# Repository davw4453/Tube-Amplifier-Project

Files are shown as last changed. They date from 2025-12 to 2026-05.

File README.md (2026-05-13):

# Tube-Amplifier-Project
This is a vacuum tube amplifier with modular input modules to provide for different audio source methods. This project was designed for my captsone project at CCSU.

# Design Requirements 
The design requirement files created as part of the CCSU capstone program are under the DesignRequirementDocs directory. The overall requirements definition is in RequirementsDefinition_DavidWrinn.odt. Each individual module of the system is defined in their respective hardware component specification file. 

# CAUTION
This project uses non-isolated high-voltage US mains power (120V). Be careful of electric shock when constructing and servicing. 

# Build Procedure
These are the steps to construct the project.

1. Have the mainboard and aux input module manufactured at your fab house of choice (JLCPCB, OshPark, etc.).

Mainboard Gerbers: EDAFiles/KiCAD_SCH/tubeAmp/gerbers/
Aux Module Gerbers: EDAFiles/KiCAD_SCH/auxModule/auxModule/gerbers/

2. Assemble the PCBs according to the component designators in the BOM: BOM/tubeAmp_BOM.ods

3. 3D print the case and lid. You can load tubecase.stl and tubecase-lid.3MF into a slicer and print in the material of choice. (I used BambuStudio and printed in clear PLA). The .3mf files are the BambuStudio project files. The .sldprt and .slddrw files are Solidworks CAD files as that is what application I used to design the case and lid. 

4. Mount the boards and components into the case. The mainboard is mounted on M3 standoffs with M3 screws. The lid also uses M3 screws. The speakers are affixed with M4-.70 x 16 screws. The input module should slice in place from the side.

5. Insert a 1A fuse into the power jack, plug in, and enjoy.

Pictures for reference can be found in the Pictures directory. 

# Problems 

- A list of problems can be found in problems.txt.
- Due to inrush current, I had to put an ICL thermistor inline from the main wall supply before the 170VDC rectifier. The part I used was: Vishay Ametherm SL1522102. https://www.digikey.com/en/products/detail/vishay-ametherm/SL1522102/1873476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 
- In a future revision I hope to increase the supply voltage from 170VDC to 300VDC to allow for more power output. 

© 2026 David Wrinn. This work is licensed under CC BY-NC-SA 4.0

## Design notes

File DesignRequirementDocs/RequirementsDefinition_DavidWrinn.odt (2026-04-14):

# System Requirements Definition

## 1. Introduction

### 1.1 Purpose

This document specifies the system requirements for the Vacuum Tube audio amplifier. Its purpose is to transform the high-level stakeholder requirements into a technical view of a required product, defining what the system must possess and how it must perform from a supplier's perspective.

## 2. System Overview

### 2.1 System Boundary and Operational Environment

This section defines the functional boundary of the system. This establishes the expected system behavior at its boundary.

System's Stimuli and Responses

The following user inputs to the system shall be:

- Connect the desired audio source (eg. Phone, CD Player) to the system via line audio connection.
- Tune the desired gain using the provided knob.
- Tune the desired volume level using the provided knob.
- Tune the desired bass level using the provided knob.
- Tune the desired treble level using the provided knob.

The following output responses of the system will be:

- Audio Playback.
  Required Interactions and Interface Constraints

The system constraints are:

- Thermal – The system is not required to be operable below 0°C or above 85°C.
- Electrical – The system is only required to support a power supply of 120V AC.
  Operational Environment

The system will be designed to operate in a primarily indoor environment around room temperature (25°C). It shall also be required to be operable in a mild outdoor environment within the temperatures specified above.

## 3. System Requirements Specification

This section details the required characteristics, attributes, and functional and performance requirements for the product solution.

### 3.1 Functional Requirements

The functions that the system is required to perform are defined as follows:

ID | Function/Requirement Description | Performance/Quantitative Measure
DW-001 | The sound level of the system shall reach at minimum 79 dB SPL | 79dB shall be measured using a sound level test device.
DW-002 | There shall be provisions to attach modules for three types of audio sources: FM Radio, Bluetooth connection, line input via 3.5mm TRS jack. These modules shall be pluggable | The connection provision shall be present on the system and identified.
DW-003 | One of the input modules shall be implemented at time of product launch | Module is present on system.
DW-004 | The gain shall be adjustable at minimum from 0dB to 23 dB through a turn-knob. | Knob is present on the system, identified, and adjusts required level.
DW-005 | The volume shall be adjustable from 10% to 100% signal level through a turn-knob. | Knob is present on the system, identified, and adjusts required level.
DW-006 | The bass shall be adjustable at minimum from -6dB to 6dB through a turn-knob. | Knob is present on the system, identified, and adjusts required level.
DW-007 | The treble shall be adjustable at minimum from -6dB to 6dB through a turn-knob. | Knob is present on the system, identified, and adjusts required level.
DW-008 | The system shall be powered by US mains via a NEMA 1-15 or 5-15P. | The plug is present in the system.

### 3.2 Non-Functional Requirements

The non-functional requirements that the system is required to adhere to are defined as follows:

ID | Requirement Description | Quantitative Measure
DW-009 | All Vacuum tubes in the system shall be visible outside of the product case. | The tubes are visible
DW-010 | Vacuum tubes are connected to the system via socket to allow for easy replacement. | The tubes are socketed.
DW-011 | Schematics are available for troubleshooting purposes | The schematics can be easily found online.
DW-012 | All design files are readily accessible, including but not limited to PCB CAD files, 3d printed case files, analysis and design process documents, BOM. | All design files can be found online in the same location as the schematics.
DW-013 | Project shall be released to the internet via public github and CC BY-NC-SA 4.0 licensed. | Project accessible through github publicly and released with CC BY-NC-SA 4.0 licensing.
DW-014 | The project shall cost at or less than the price of 59 McDonald’s Big Macs to produce | The final constructed unit is produced for at or less than the given price.

## 4. Requirements Analysis and Verification Basis

### 4.1 Integrity

This section demonstrates the process for verification.

#### 4.1.1 Verification Basis

The system requirements will be satisfied and assessed. The following requirements will be verified in the following methods.

- Sound level – A testing apparatus will be used to ensure the sound output reaches 79 dB SPL.
- The input module connections will be present.
- All control knobs will be present.
- The Power connection will be present and accessible.
- All vacuum tubes in the system shall be visible and easily replaced via socket.
- The location of design files shall be known and navigable via the internet.

## 5. Functional Diagram

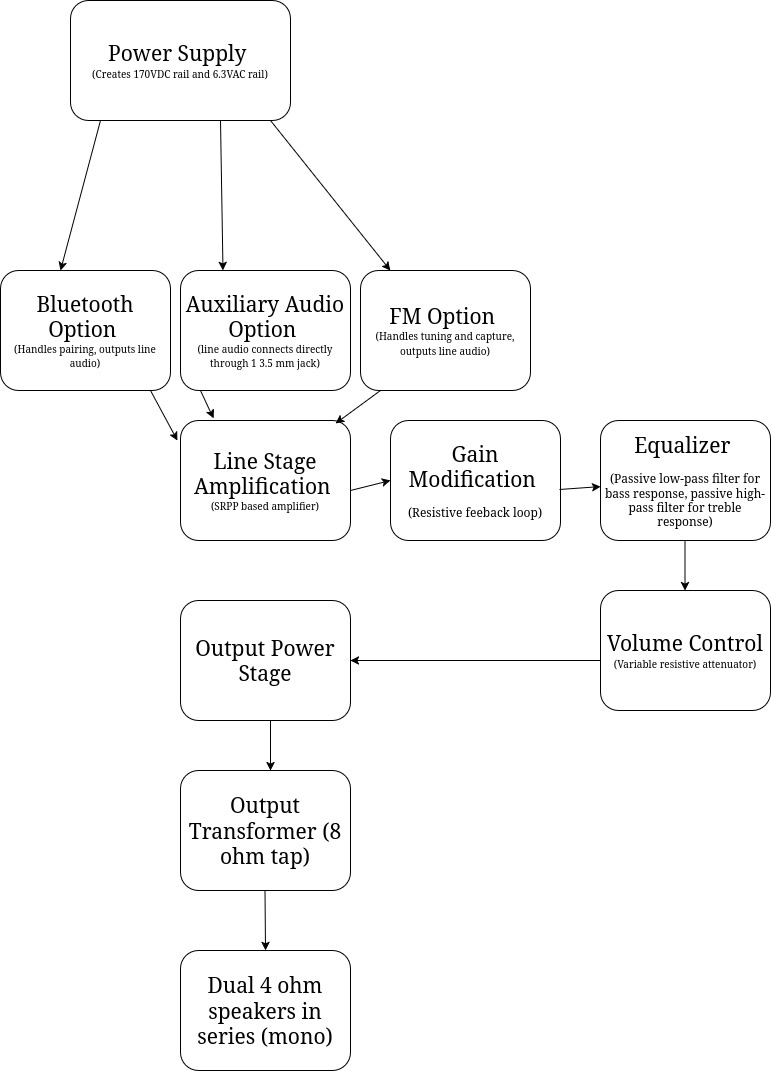
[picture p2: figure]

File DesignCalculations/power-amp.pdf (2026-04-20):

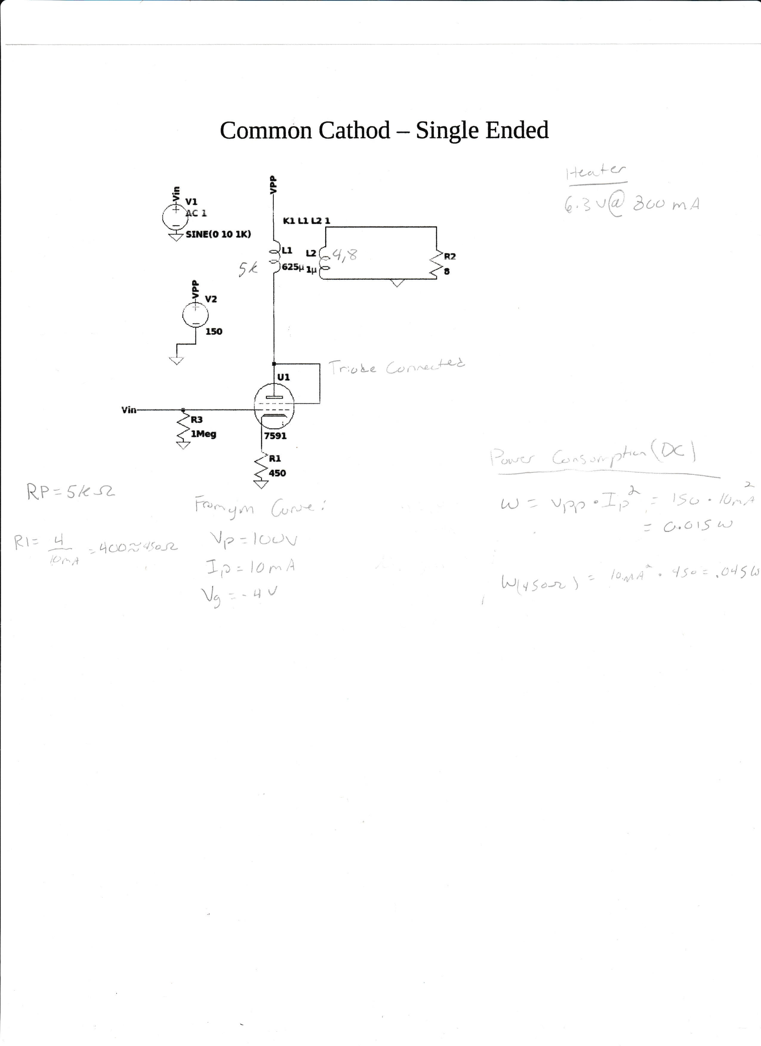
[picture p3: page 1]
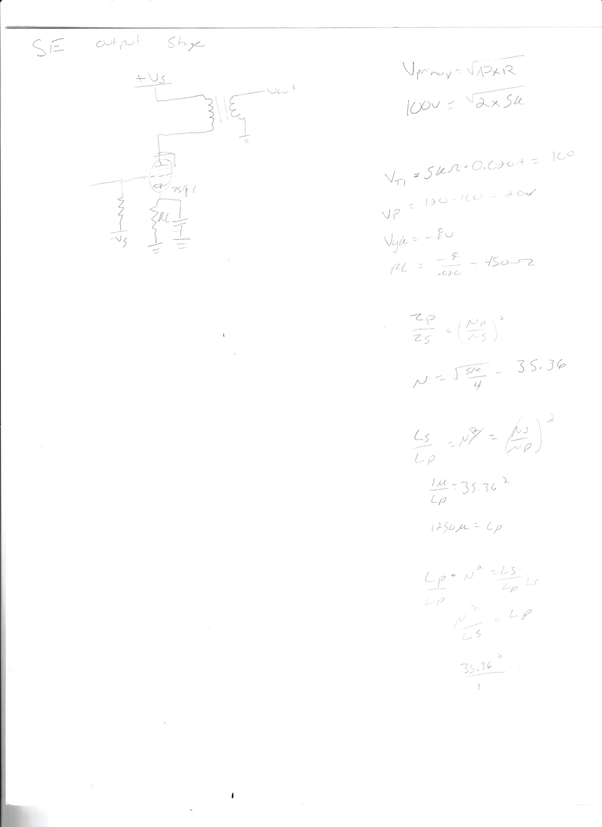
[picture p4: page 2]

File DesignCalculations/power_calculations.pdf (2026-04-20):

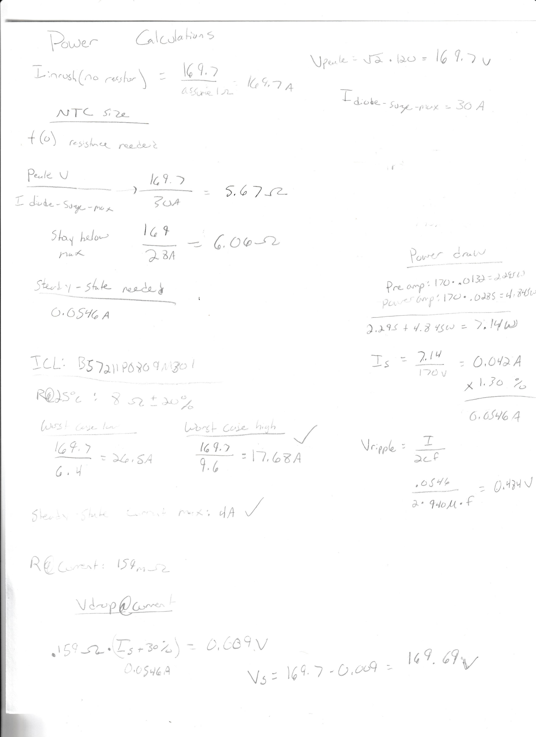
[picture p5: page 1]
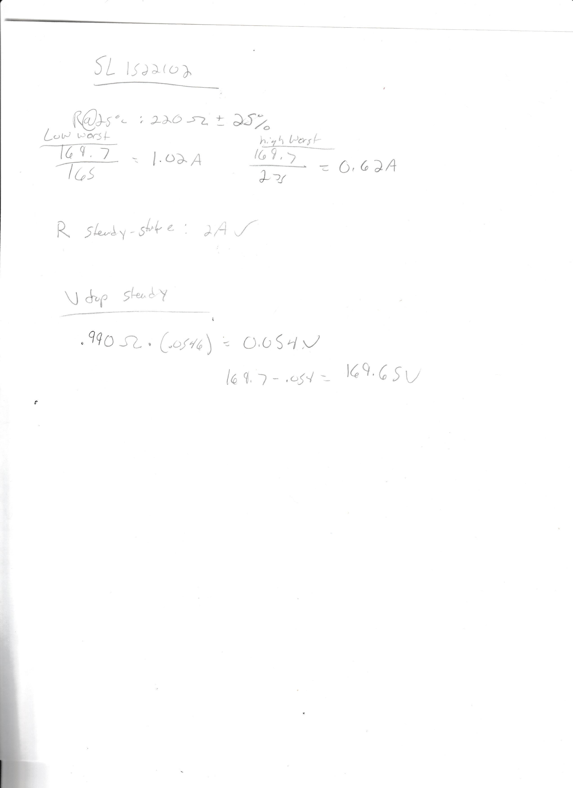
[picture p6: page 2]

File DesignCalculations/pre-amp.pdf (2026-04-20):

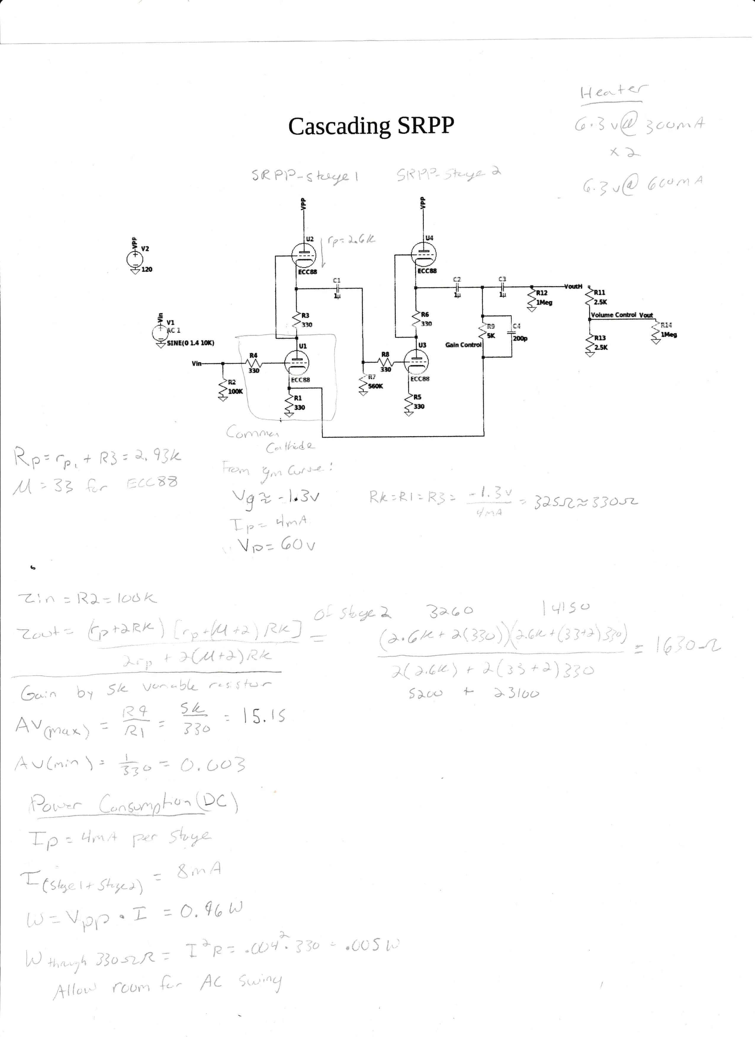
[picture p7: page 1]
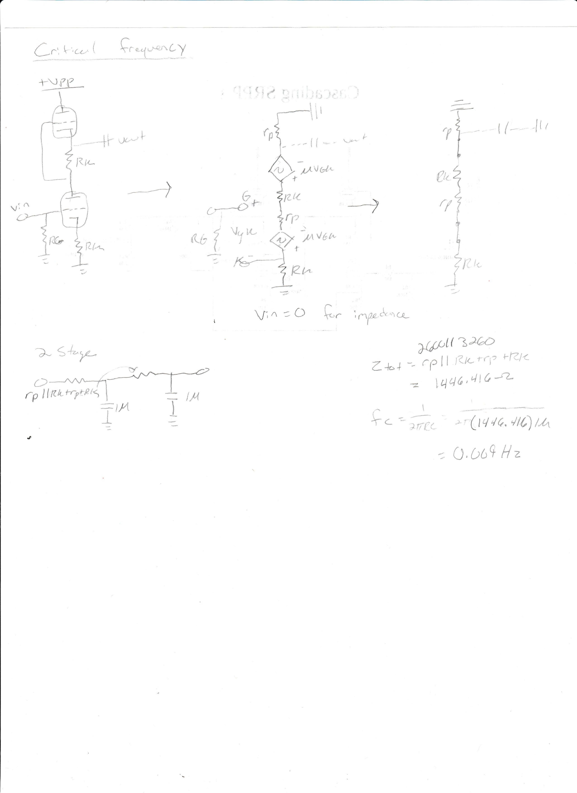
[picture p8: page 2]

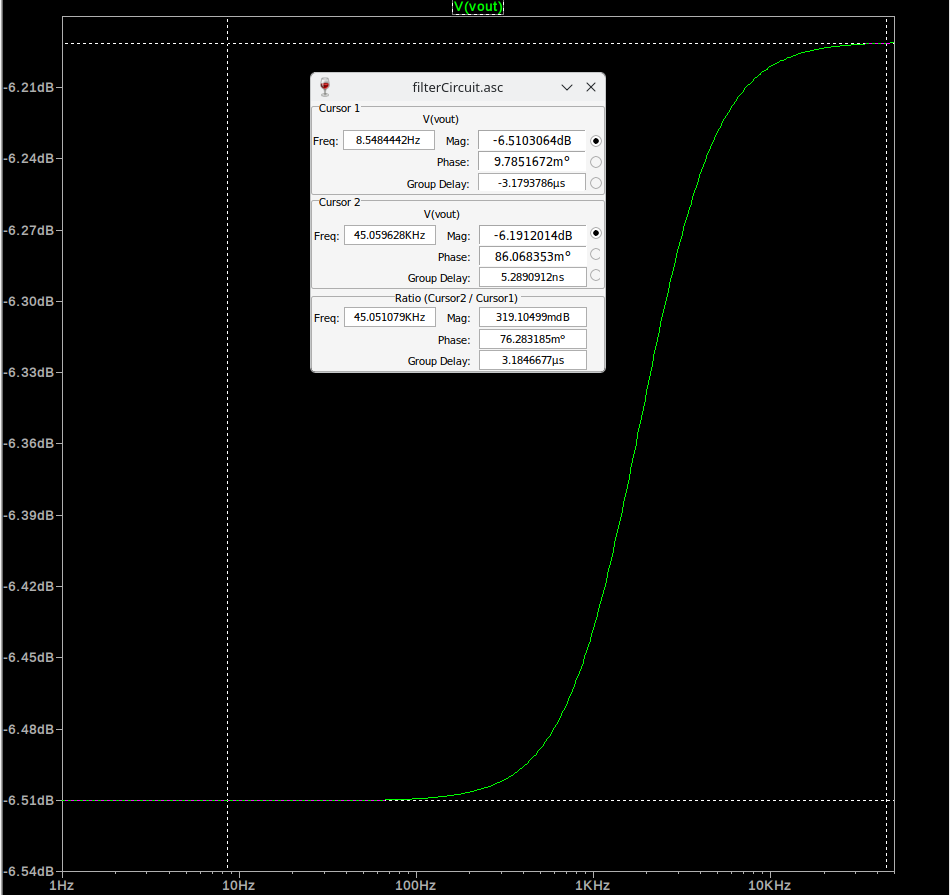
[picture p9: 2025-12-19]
SimulationScreenshots/tonecontrol_flat.png

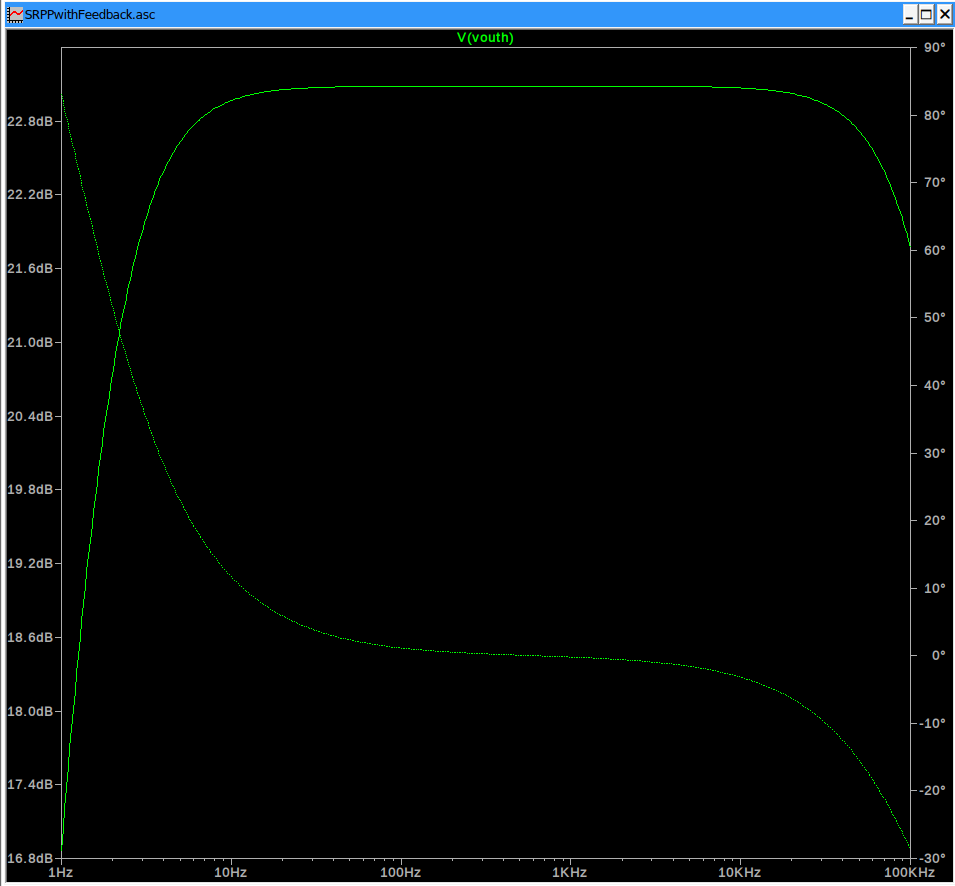
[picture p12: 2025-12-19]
SimulationScreenshots/SRPPwithfeedback_response.png

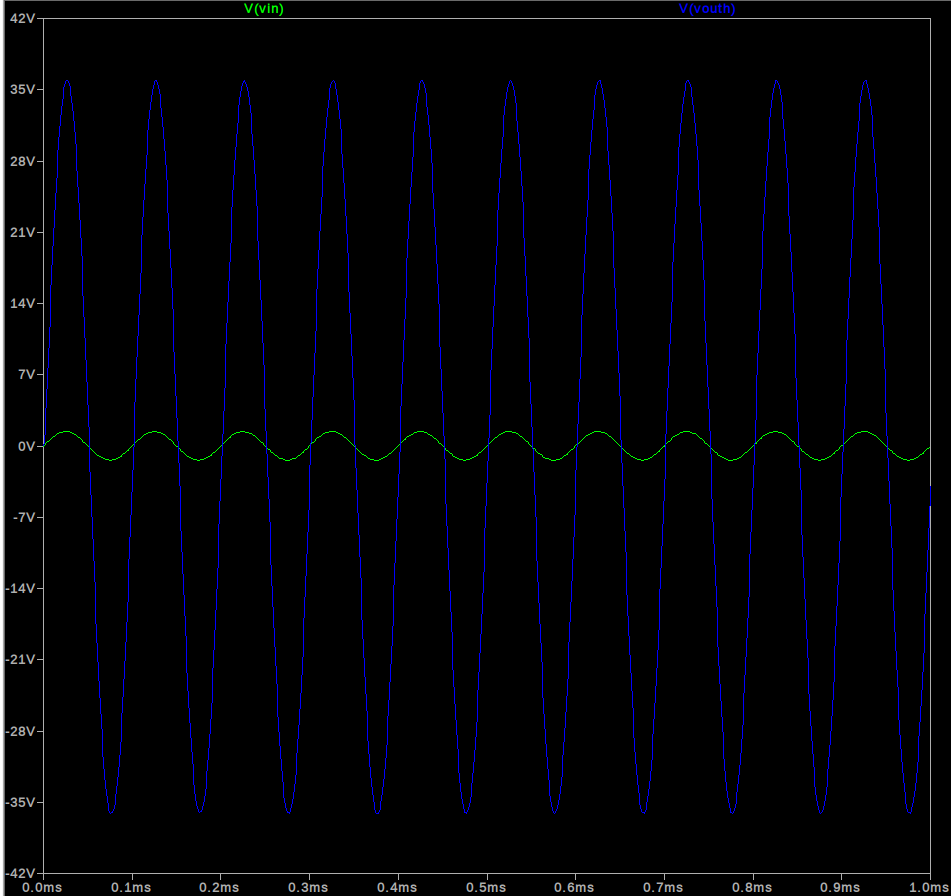
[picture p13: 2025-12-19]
SimulationScreenshots/SRPP_fullgain.png

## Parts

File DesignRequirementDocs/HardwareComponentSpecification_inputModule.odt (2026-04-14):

Hardware Component Specification – Input Module

# Overview and Perspective

## Overview and Key Functions of System

This system is a credit card sized expansion card slot to provide the input signal to the system. It will have a single connector to supply the following to the expansion card: 170VDC, Ground, 6.3VAC (two pin differential), and an auxiliary input signal. A stereo audio signal will be summed together through two 1K resistors to create a mono audio signal for the line-stage amplifier.

## Overview and Purpose of Hardware Component

The purpose of this component is to provide an audio signal to the amplifier, regardless of the source of that audio signal.

## Component Perspective

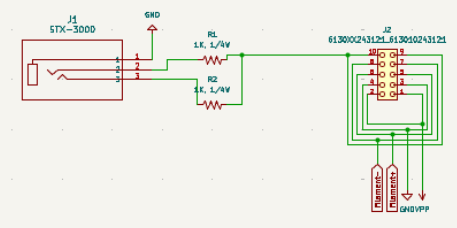
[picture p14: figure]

# Component Details

## Component Part Specification

- Qty. 1 10 Pin IDC connector.

## Signal/Communication Interface(s)

Output:

- Auxiliary Audio

## Power Interface(s)

Input:

- 170VDC power rail
- 6.3VAC power rail

## Key Properties/Functions

The system will output an auxiliary audio signal.

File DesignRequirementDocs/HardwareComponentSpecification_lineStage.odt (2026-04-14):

Hardware Component Specification – Line Stage

# Overview and Perspective

## Overview and Key Functions of System

This system is the first point of contact to amplify an auxillary signal. It is formed by two cascaded SRPP amplifier stages using a 6922/ECC88 dual triode vacuum tube. There is a negative feedback loop fed from the output to the cathode of the first SRPP stage. Gain is controlled by potentiometer RV1, which is a 10K potentiometer with one end bridged to the center, creating a 5K variable resistor. Gain is effectively RV1/R3. The Gain factor can be scaled from 0.003 to 15.15.

## Overview and Purpose of Hardware Component

The purpose of this component is to amplify an auxiliary audio signal to be a suitable level for the power amplification stage and to compensate for the losses from the passive filter circuit.

## Component Perspective

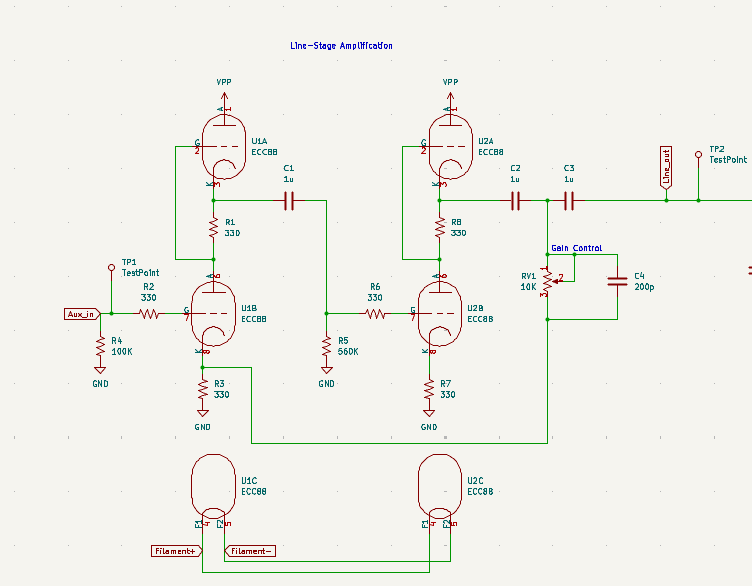
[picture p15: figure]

# Component Details

## Component Part Specification

- Qty. 2 ECC88 vacuum tubes
- Qty. 6 330 ohm 1/4W resistors
- Qty. 1 100K ohm 1/4W resistors
- Qty. 1 560K ohm 1/4W resistors
- Qty. 3 1uF 200V capacitors
- Qty. 1 10K ohm potentiometer
- Qty. 1 200pF 200V capacitor

## Signal/Communication Interface(s)

Input:

- Auxiliary Audio

Output:

- Post line-stage audio signal

## Power Interface(s)

Input:

- 170VDC power rail

## Key Properties/Functions

The system will output an amplified audio signal.

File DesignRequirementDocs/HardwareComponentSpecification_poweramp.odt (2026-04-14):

Hardware Component Specification – Power Amplification

# Overview and Perspective

## Overview and Key Functions of System

This system is the last amplification stage before the audio signal reaches the speaker. It is a single-ended class A amplifier formed by a single stage. The amplifying stage is a triode-connected tetrode vacuum tube in a common-cathode configuration. It feeds an audio transformer to convert the high output impedance from the vacuum tube to a low impedance compatible with 4 and 8 ohm speakers.

## Overview and Purpose of Hardware Component

The purpose of this component is to provide the output power to drive a speaker.

## Component Perspective

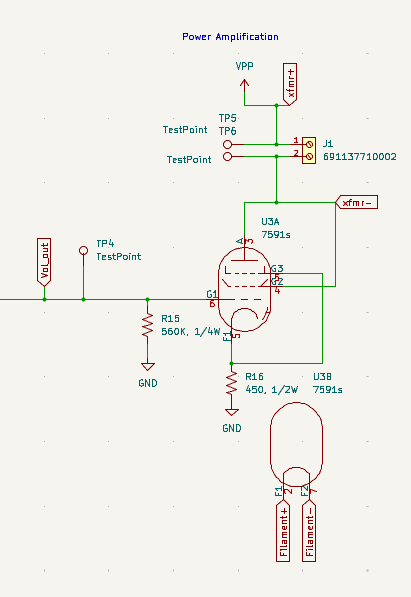
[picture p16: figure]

# Component Details

## Component Part Specification

- Qty. 1 560K 1/4W resistor
- Qty. 1 450 1/2W resistor
- Qty. 1 7591 tetrode vacuum tube
- Qty. 1 OT8SE+ audio transformer

## Signal/Communication Interface(s)

Input:

- post-volume control audio signal

Output:

- Amplified Audio signal to speaker

## Power Interface(s)

Input:

- 170VDC power rail

## Key Properties/Functions

The system will transfer 0-2W of power to a 4 ohm speaker.

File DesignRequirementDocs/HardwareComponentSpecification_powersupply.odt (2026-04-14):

Hardware Component Specification – Power Supply

# Overview and Perspective

## Overview and Key Functions of System

This system is comprised of a filtered full-wave rectifier and a transformer. The rectifier will output 170VDC given a 170Vpp 60 Hz input with a ripple voltage of 51 mV. The transformer will output 6.3VAC given the same 170Vpp input power. The whole system will be capable of delivering 15.5 watts. (Modified to add ICL in-line before C7 and C8 to limit inrush current to around 772 mA.)

## Overview and Purpose of Hardware Component

The purpose of this component is to provide power to all of the sub-circuits of the system.

## Component Perspective

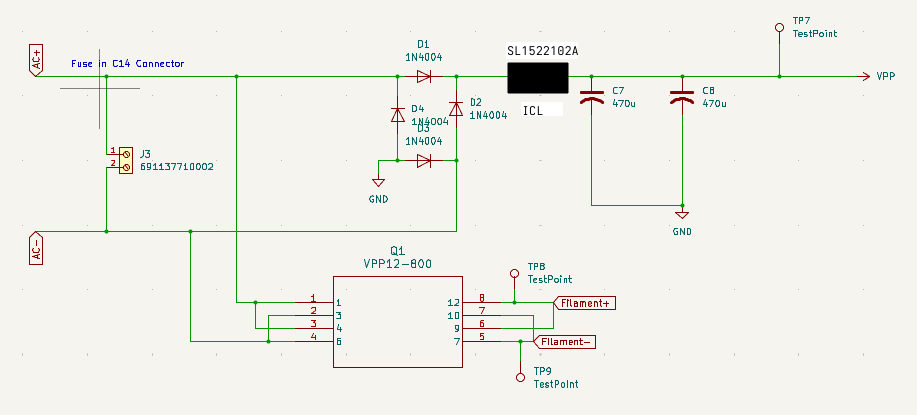
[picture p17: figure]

# Component Details

## Component Part Specification

- Qty. 4 1n4004 diodes
- Qty. 1 Fused C14 connector
- Qty. 1 200 mA fuse
- Qty. 1 120→6.3 V power transformer
- Qty. 2 470uF electrolytic capacitors 200V
- Qty. 1 SL1522102A ICL

## Power Interface(s)

Input:

- North American 120Vrms main power

Output:

- 170VDC power rail
- 6.3VAC power rail

## Key Properties/Functions

The system will transform 120Vrms main power into 170VDC and 6.4VAC derived rails.

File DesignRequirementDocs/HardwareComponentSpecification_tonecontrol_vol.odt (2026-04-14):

Hardware Component Specification – Line Stage

# Overview and Perspective

## Overview and Key Functions of System

This system allows the user to adjust the bass response, treble response, and volume level as desired. It is a passive system, which means the output voltage will be lower than the input voltage. For all three control dials, a 10K potentiometer is used. The bass and treble are adjustable to +/- 6dB. The volume control can attenuate the signal from 0% to 100% with steps of 1%.

## Overview and Purpose of Hardware Component

The purpose of this component is to adjust the bass characteristics, the treble characteristics, and the volume level per the listener’s preference.

## Component Perspective

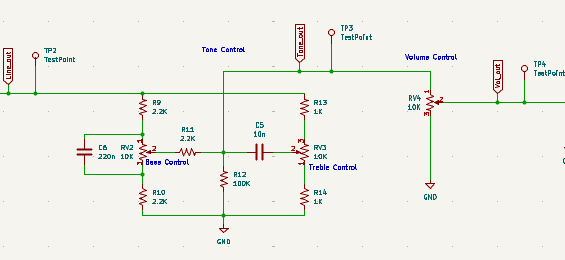
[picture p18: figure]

# Component Details

## Component Part Specification

- Qty. 3 2.2K 1/4W resistors
- Qty. 2 1K 1/4W resistors
- Qty. 1 220nF 50V capacitor
- Qty. 1 10nF 50V capacitor
- Qty. 1 100K ¼W resistor
- Qty. 2 10K ohm potentiometer

## Signal/Communication Interface(s)

Input:

- Post-Line stage audio signal

Output:

- tuned post-line stage audio signal.

## Power Interface(s)

none

## Key Properties/Functions

The system will output a tuned audio signal suitable for power amplification.

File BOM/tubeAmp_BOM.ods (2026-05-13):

MainBoard
Reference | Qty | Value | Footprint | Manufacturer PN | Link | Unit Price | Ext. Price
C1,C2,C3 | 3 | 1u, 100V | Capacitor_THT:CP_Radial_D5.0mm_P2.00mm | ESK105M100AC3AA | https://www.digikey.com/en/products/detail/kemet/esk105m100ac3aa/18167477 | $0.16 | $0.48
C4 | 1 | 200p, 50V | Capacitor_THT:C_Rect_L7.2mm_W5.5mm_P5.00mm_FKS2_FKP2_MKS2_MKP2 | C317C201J5G5TA7301 | https://www.mouser.com/ProductDetail/KEMET/C317C201J5G5TA7301?qs=2FIyTMJ0hNno2fk56OoQRA%3D%3D | $0.62 | $0.62
C5 | 1 | 10n, 50V | Capacitor_THT:C_Rect_L7.2mm_W5.5mm_P5.00mm_FKS2_FKP2_MKS2_MKP2 | FG28C0G1H103JNT06 | https://www.digikey.com/en/products/detail/tdk-corporation/FG28C0G1H103JNT06/5803088 | $0.35 | $0.35
C6 | 1 | 220n, 50V | Capacitor_THT:C_Rect_L7.2mm_W5.5mm_P5.00mm_FKS2_FKP2_MKS2_MKP2 | FG22C0G1H224JNT00 | https://www.digikey.com/en/products/detail/tdk-corporation/FG22C0G1H224JNT00/7326573 | $1.47 | $1.47
C7,C8 | 2 | 470u, 200V | Capacitor_THT:CP_Radial_D18.0mm_P7.50mm | EPAG201ELL471MM40S | https://www.digikey.com/en/products/detail/chemi-con/EPAG201ELL471MM40S/3983309 | $3.02 | $6.04
D1,D2,D3,D4 | 4 | 1N4004 | Diode_THT:D_DO-41_SOD81_P10.16mm_Horizontal | 1N4004 | https://www.mouser.com/ProductDetail/Diotec-Semiconductor/1N4004?qs=OlC7AqGiEDk3eaZusDVIWQ%3D%3D | $0.10 | $0.40
J1,J3 | 2 | 691137710002 | DavidWrinn:691137710002-2screw | 691137710002 | https://www.digikey.com/en/products/detail/w%C3%BCrth-elektronik/691137710002/6644051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 | $0.36 | $0.72
J2 | 1 | 702471054 | DavidWrinn:CONN_7024710xx_10pos | 702471054 | https://www.digikey.com/en/products/detail/molex/0702471054/3302078?s=N4IgTCBcDaIOwAYwBY4EYEFZkgLoF8g | $2.37 | $2.37
Q1 | 1 | VPP12-800 | DavidWrinn:TRANS_VPP12-800_TRM | VPP12-800 | https://www.digikey.com/en/products/detail/triad-magnetics/VPP12-800/242498 | $10.06 | $10.06
R1,R2,R3,R6,R7,R8 | 6 | 330, 1/4W | Resistor_THT:R_Axial_DIN0207_L6.3mm_D2.5mm_P10.16mm_Horizontal | CF14JT330R | https://www.digikey.com/en/products/detail/stackpole-electronics-inc/CF14JT330R/1741399 | $0.10 | $0.60
R4,R12 | 2 | 100K, 1/4W | Resistor_THT:R_Axial_DIN0207_L6.3mm_D2.5mm_P10.16mm_Horizontal | CF14JT100K | https://www.digikey.com/en/products/detail/stackpole-electronics-inc/CF14JT100K/1741263 | $0.10 | $0.20
R5,R15 | 2 | 560K, 1/4W | Resistor_THT:R_Axial_DIN0207_L6.3mm_D2.5mm_P10.16mm_Horizontal | CF14JT560K | https://www.digikey.com/en/products/detail/stackpole-electronics-inc/CF14JT560K/1741468 | $0.10 | $0.20
R9,R10,R11 | 3 | 2.2K, 1/4W | Resistor_THT:R_Axial_DIN0207_L6.3mm_D2.5mm_P10.16mm_Horizontal | CF14JT2K20 | https://www.digikey.com/en/products/detail/stackpole-electronics-inc/CF14JT2K20/1741321 | $0.10 | $0.30
R13,R14 | 2 | 1K, 1/4W | Resistor_THT:R_Axial_DIN0207_L6.3mm_D2.5mm_P10.16mm_Horizontal | CF14JT1K00 | https://www.digikey.com/en/products/detail/stackpole-electronics-inc/CF14JT1K00/1741314 | $0.10 | $0.20
R16 | 1 | 450, 1/2W | Resistor_THT:R_Axial_DIN0309_L9.0mm_D3.2mm_P12.70mm_Horizontal | MFR50SFTE52-442R | https://www.digikey.com/en/products/detail/yageo/MFR50SFTE52-442R/9151526 | $0.10 | $0.10
RV1,RV2,RV3,RV4 | 4 | 10K, 1/4W | Connector_PinHeader_2.54mm:PinHeader_1x03_P2.54mm_Vertical | PTN24B-B1015K1PB | https://www.digikey.com/en/products/detail/same-sky-formerly-cui-devices/PTN24B-B1015K1PB/22255103 | $1.45 | $5.80
TP1,TP2,TP3,TP4,TP5,TP6,TP7,TP8,TP9 | 9 | TestPoint | TestPoint:TestPoint_Pad_D1.5mm
U1,U2 | 2 | ECC88 | Valve:Valve_Noval_P | 6922EH | https://www.vivatubes.com/brand-new-gain-tested-electro-harmonix-6922-6dj8-vacuum-tube/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 | $21.92 | $43.84
U3 | 1 | 7591s | Wheat:OCTAL | 7591S | https://www.vivatubes.com/new-jj-7591-vacuum-tube/?searchid=0&search_query=7591s | $28.37 | $28.37
U1,U2 Socket | 2 | ECC88 |  | B9A | https://www.amazon.com/lanema-Ceramic-Mount-Socket-Vacuum/dp/B0CGTVRS7P | $1.02 | $2.04
U3 Socket | 1 | 7591s |  | Octal | https://www.amazon.com/JEMOSA-Bakelite-Amplifier-Vacuum-Protect/dp/B0CCMGSRRD | $2.95 | $2.95
External Connections
Reference | Qty | Value | Footprint | Manufacturer PN | Link | Unit Price
F1 | 1 | 1A |  | Need to choose PN | 1A 5mm x 20mm fuse | $1.19 | $1.19
J1 | 1 | 723W-X2/04 |  | 723W-X2/04 | https://www.digikey.com/en/products/detail/qualtek/723W-X2-04/245547?s=N4IgTCBcDaIOxgMwHcC0APMB6ADAFhAF0BfIA | $2.67 | $2.67
LS1,LS2 | 2 | 4 |  | CSS-10237-54 | https://www.digikey.com/en/products/detail/same-sky-formerly-cui-devices/CSS-10237-54/12762237 | $8.28 | $16.56
TR1 | 1 | MPS OT8SE+ | Transformer_THT:Transformer_Breve_TEZ-22x24 | MPS OT8SE+ | https://www.ebay.com/itm/167716877031?_skw=musical+power+supplies+ot8se%2B&itmmeta=01K9FETDF6CQ9TKCFDS6SRV0VM | $34.95 | $34.95
 | 1 | 22AWG, 25’ |  | 8023 | https://www.digikey.com/en/products/detail/sparkfun-electronics/08023/6833929 | $3.44 | $3.44
 | 1 | Spade connector 6.3mm, 100 pack |  | Baomain 100-Pack | https://www.amazon.com/Baomain-disconnects-Insulated-Connector-Electrical/dp/B01G4POUAU | $6.64 | $6.64
 | 1 | Clear PLA |  | Elegoo Translucent PLA | https://www.amazon.com/ELEGOO-Filament-Translucent-Dimensional-Cardboard/dp/B0DM1QTZKN | $18.99 | $18.99
 | 1 | 4pcs Aluminum Knobs |  | 4Pcs Aluminum Knobs | https://www.amazon.com/gp/aw/d/B0B2ZYBPXB/?aaxitk=a0cbd2bfeb396e95dc7557d5a0cb5391&hsa_cr_id=0 | $17.99 | $17.99
SW1 | 1 | SW_SPST |  | MTS-101 | https://www.amazon.com/dp/B0799LBFNY?th=1 | $0.80 | $0.80
Aux Input Module
Reference | Qty | Value | Footprint | Manufacturer PN | Link | Unit Cost
J1 | 1 | STX-3000 | STX-3000_KYC | STX-3000 | https://www.digikey.com/en/products/detail/kycon-inc/STX-3000/9975995?s=N4IgTCBcDaIMoBUAaBaAzABiyAugXyA | $0.64 | $0.64
J2 | 1 | 6130XX243121_613010243121 | DavidWrinn:613010243121_10pin | 613010243121 | https://www.digikey.com/en/products/detail/w%C3%BCrth-elektronik/613010243121/2508634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 | $1.00 | $1.00
R1,R2 | 2 | 1K, 1/4W | Resistor_THT:R_Axial_DIN0207_L6.3mm_D2.5mm_P10.16mm_Horizontal | CF14JT1K00 | https://www.digikey.com/en/products/detail/stackpole-electronics-inc/CF14JT1K00/1741314 | $0.10 | $0.20
 |  |  |  |  | Complete Sub-total (minus pcb manufacturing costs) |  | $212.18
 |  |  |  |  |  |  | $4.00

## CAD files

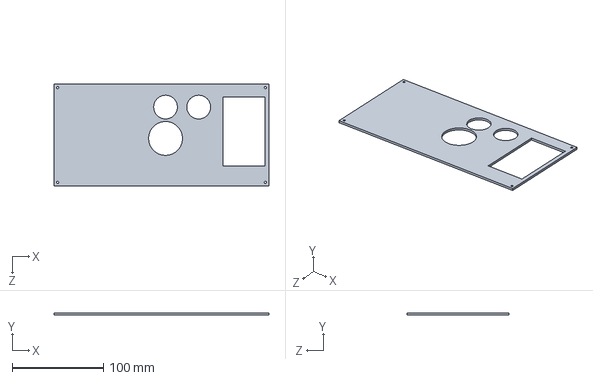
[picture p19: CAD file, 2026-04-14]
CaseDrawings/tubecase-lid.sldprt
235.9 x 2.50 x 111.9 mm

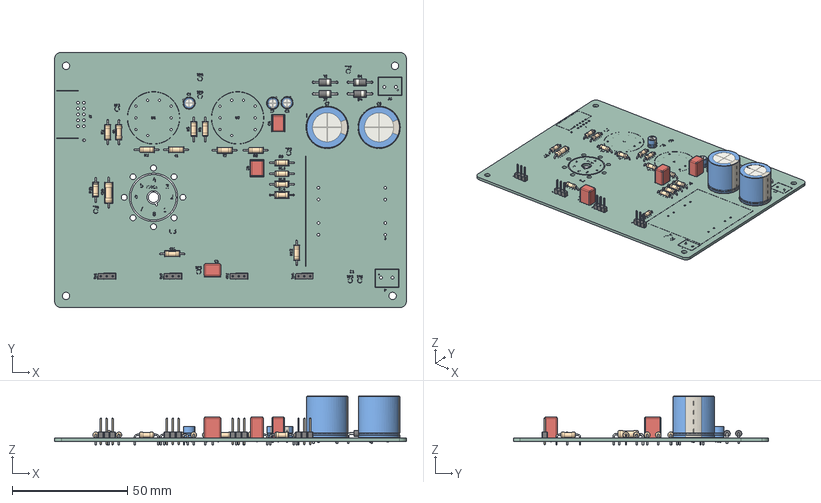
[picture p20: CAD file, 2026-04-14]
EDAFiles/KiCAD_SCH/tubeAmp/board-outline.step
152.4 x 110.6 x 21.0 mm
PinHeader_1x03_P2.54mm_Vertical x 4
D_DO-41_SOD81_P10.16mm_Horizontal x 4
R_Axial_DIN0207_L6.3mm_D2.5mm_P10.16mm_Horizontal x 15
CP_Radial_D18.0mm_P7.50mm x 2
CP_Radial_D5.0mm_P2.00mm x 3
C_Rect_L7.2mm_W5.5mm_P5.00mm_FKS2_FKP2_MKS2_MKP2 x 3
R_Axial_DIN0309_L9.0mm_D3.2mm_P12.70mm_Horizontal
tubeAmp_silkscreen x 2
tubeAmp_PCB

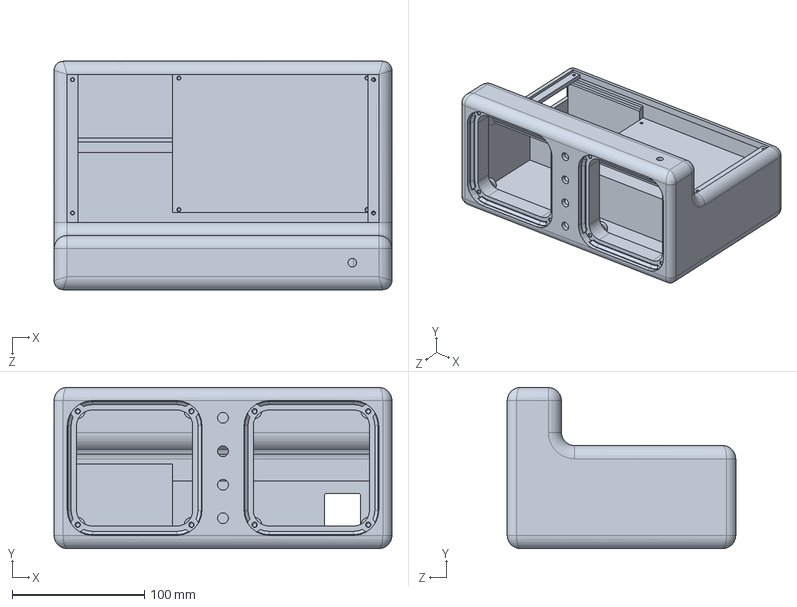
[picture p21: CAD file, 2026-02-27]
CaseDrawings/case-as-one.SLDPRT
256.0 x 122.0 x 173.1 mm

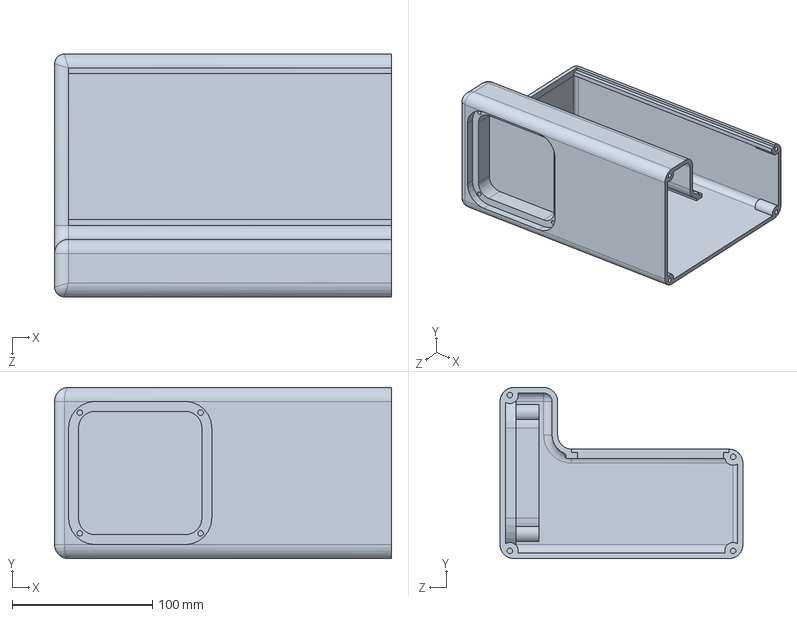
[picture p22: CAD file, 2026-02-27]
CaseDrawings/case-left.SLDPRT
240.1 x 122.0 x 173.1 mm

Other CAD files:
CaseDrawings/tubecase.3mf
CaseDrawings/case-as-one.SLDDRW
CaseDrawings/tubecase-lid.3MF
CaseDrawings/tubecase-lid.3mf
CaseDrawings/tubecase-lid.slddrw
CaseDrawings/tubecase.stl

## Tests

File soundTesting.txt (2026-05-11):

smells like teen spirit

hmdx - max 73db
beats pill - max 85.8dB
tube amp - 78.3 dB

Tested at 10ft distance

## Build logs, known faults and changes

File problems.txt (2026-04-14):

two mounting holes not bonded to ground
main power traces too thin
7591s footprint doesn't fit
6922 footprints doesn't fit well
Provision series resistor add-in to 6.3VAC secondary.
add common mode choke
add icl/soft start DC
thicken traces because it makes me feel better
pots that aren't switches

aux input module connector needs to overhang + flip sides for case.

CASE
speaker holes too small
control pots too small
input module slot to narrow
speaker indent wall doesn't print well
Case wall to thick to skrew in pot securing nuts.
lid lip overhangs PCB on power side.

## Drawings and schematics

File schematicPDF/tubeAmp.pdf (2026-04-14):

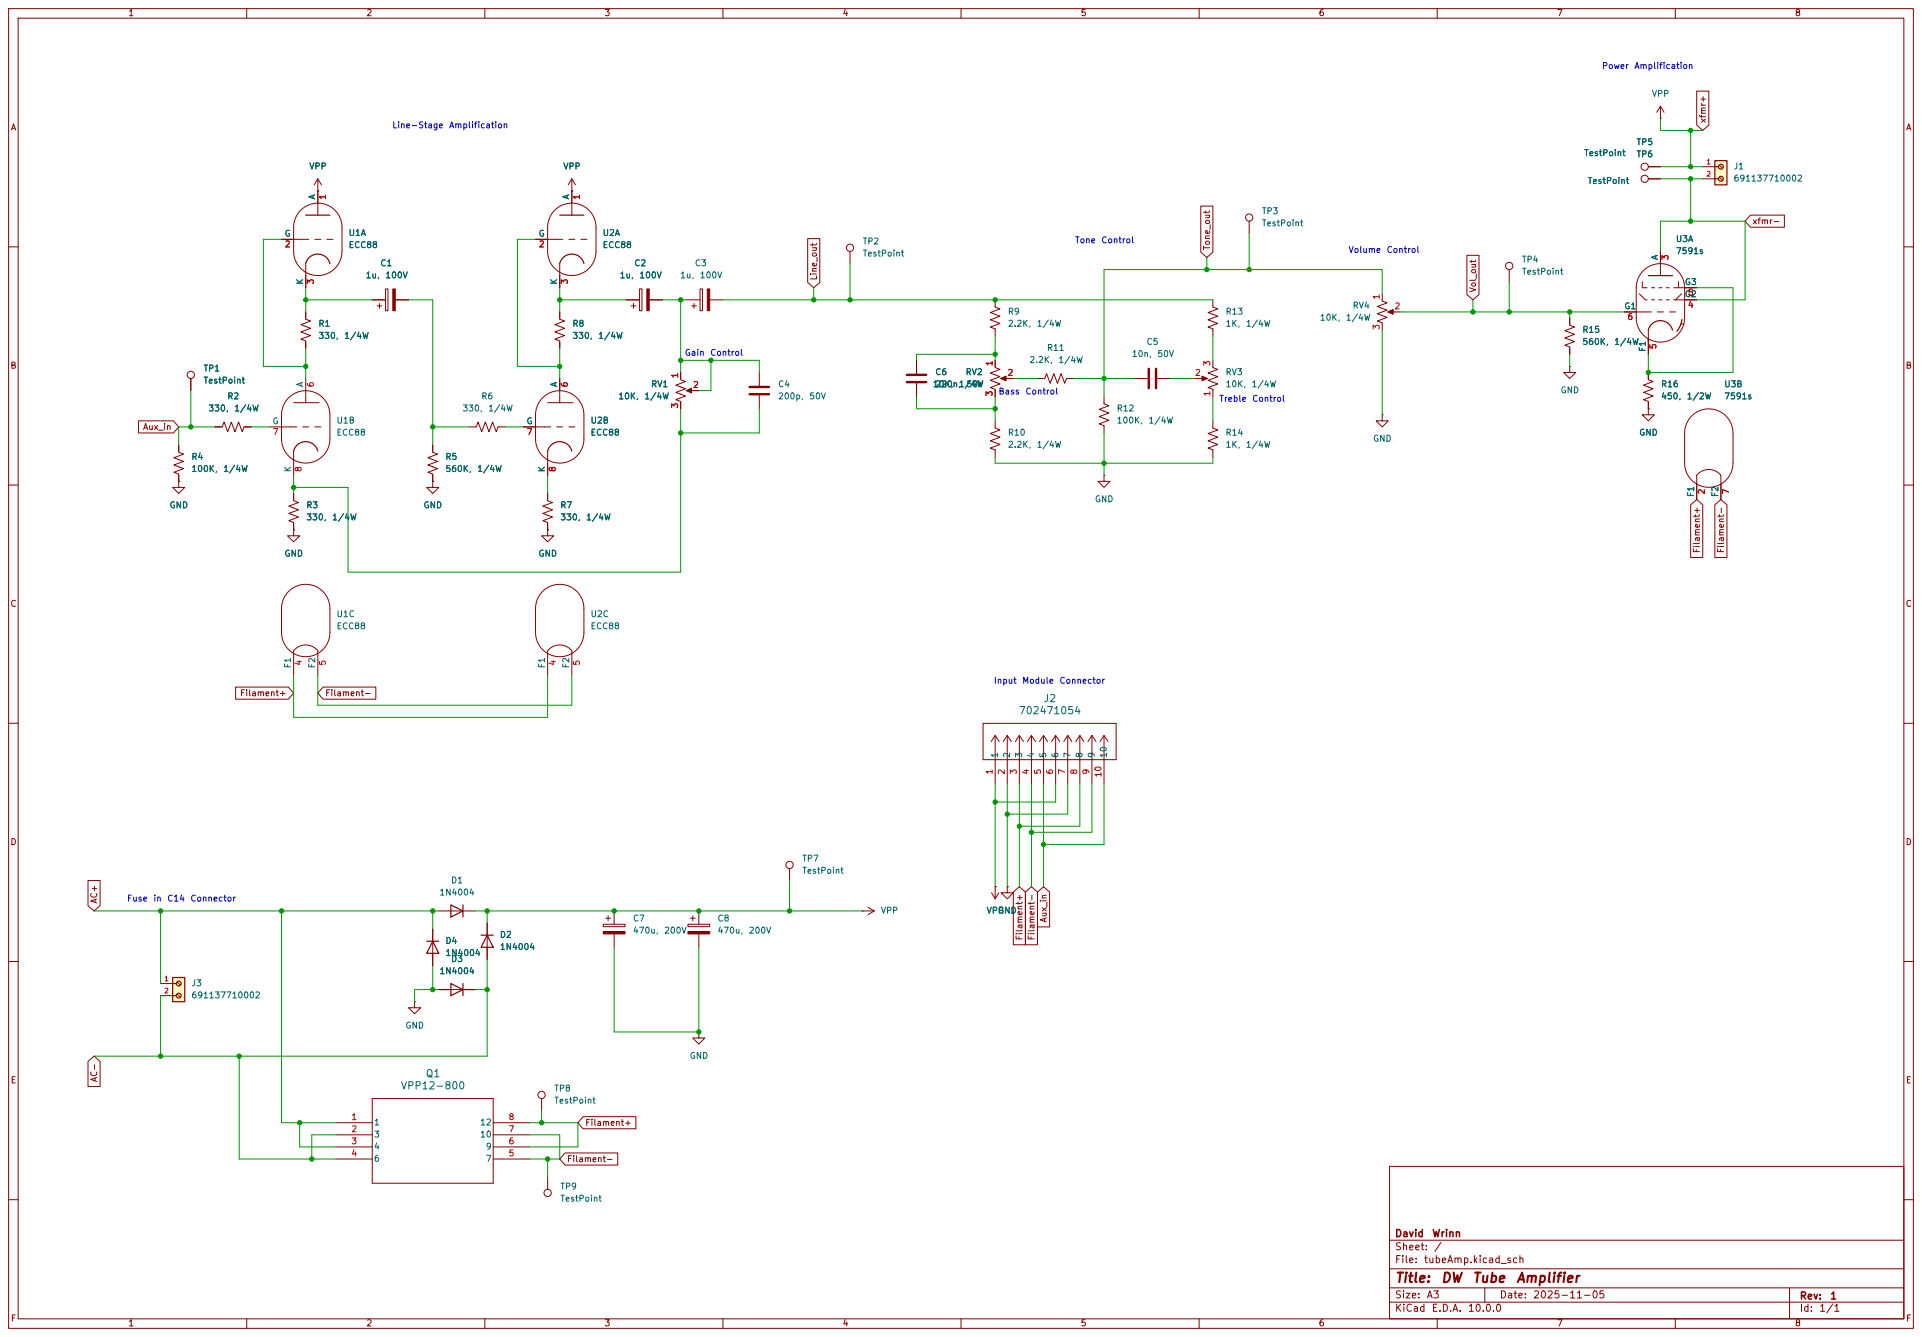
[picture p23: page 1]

Line-Stage Amplification GND

David Wrinn
Sheet: /
File: tubeAmp.kicad_sch
Title: DW Tube Amplifier

Size: A3 | Rev: 1 | F Date: 2025-11-05 KiCad E.D.A. 10.0.0

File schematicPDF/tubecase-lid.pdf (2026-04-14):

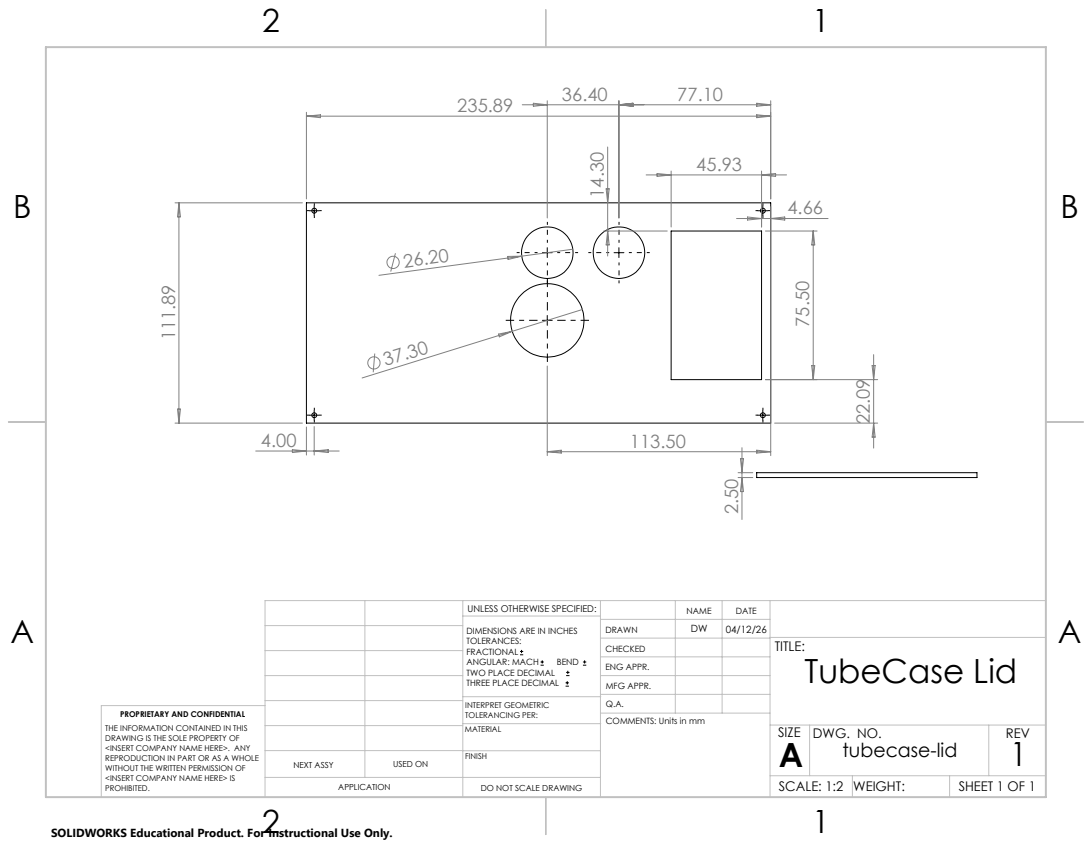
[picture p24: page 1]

UNLESS OTHERWISE SPECIFIED: | | NAME | DATE
DIMENSIONS ARE IN INCHES TOLERANCES: FRACTIONAL ANGULAR: MACH BEND TWO PLACE DECIMAL THREE PLACE DECIMAL | DRAWN | DW | 04/12/26

CHECKED | | | TITLE: TubeCase Lid

ENG APPR.
MFG APPR.

INTERPRET GEOMETRIC TOLERANCING PER: | Q.A.
MATERIAL | | SIZE A | DWG. NO. tubecase-lid | REV 1

PROPRIETARY AND CONFIDENTIAL
THE INFORMATION CONTAINED IN THIS
DRAWING IS THE SOLE PROPERTY OF
<INSERT COMPANY NAME HERE>. ANY
REPRODUCTION IN PART OR AS A WHOLE
WITHOUT THE WRITTEN PERMISSION OF
<INSERT COMPANY NAME HERE> IS
PROHIBITED.

COMMENTS: Units in mm

NEXT ASSY | USED ON | FINISH

APPLICATION | DO NOT SCALE DRAWING | | SCALE: 1:2 | WEIGHT: | SHEET 1 OF 1

SOLIDWORKS Educational Product. For Instructional Use Only.

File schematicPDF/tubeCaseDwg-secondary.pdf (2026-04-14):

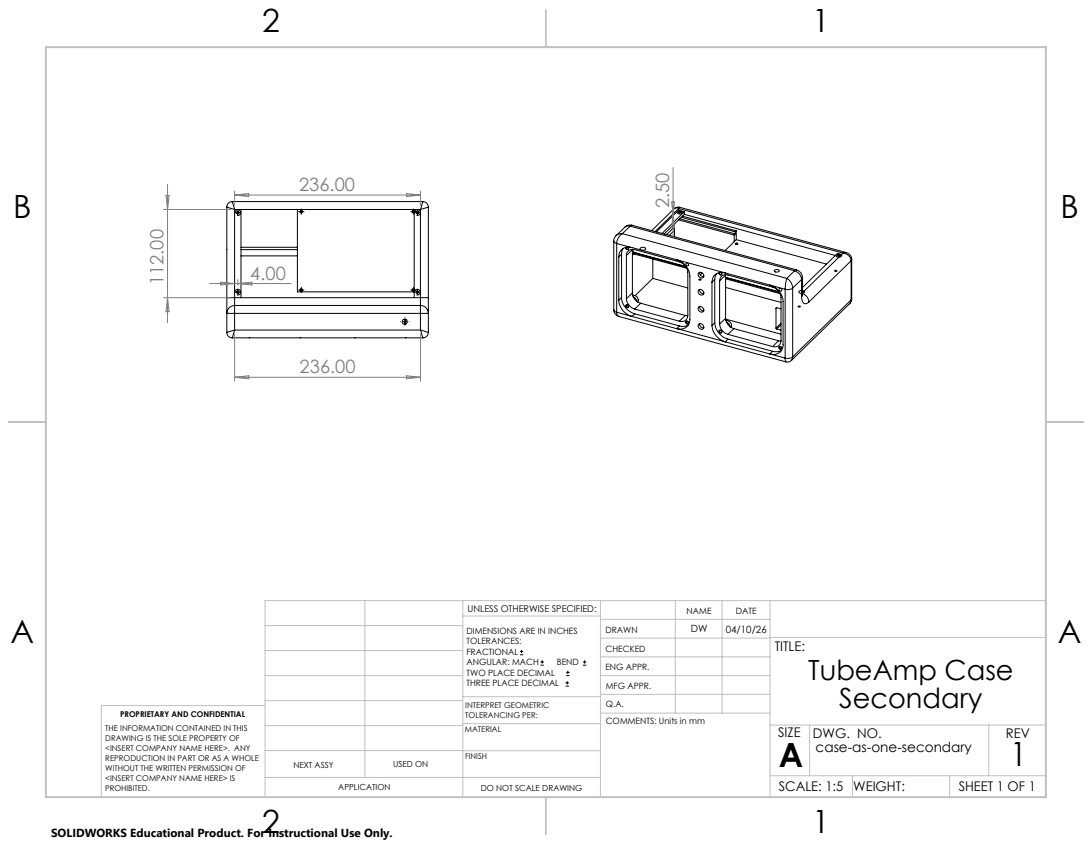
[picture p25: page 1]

UNLESS OTHERWISE SPECIFIED: | | NAME | DATE
DIMENSIONS ARE IN INCHES TOLERANCES: FRACTIONAL ANGULAR: MACH BEND TWO PLACE DECIMAL THREE PLACE DECIMAL | DRAWN | DW | 04/10/26

CHECKED | | | TITLE: TubeAmp Case Secondary

ENG APPR.
MFG APPR.

INTERPRET GEOMETRIC TOLERANCING PER: | Q.A.
MATERIAL | | SIZE A | DWG. NO. case-as-one-secondary | REV 1

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

COMMENTS: Units in mm

NEXT ASSY | USED ON | FINISH

APPLICATION | DO NOT SCALE DRAWING | | SCALE: 1:5 | WEIGHT: | SHEET 1 OF 1

SOLIDWORKS Educational Product. For Instructional Use Only.

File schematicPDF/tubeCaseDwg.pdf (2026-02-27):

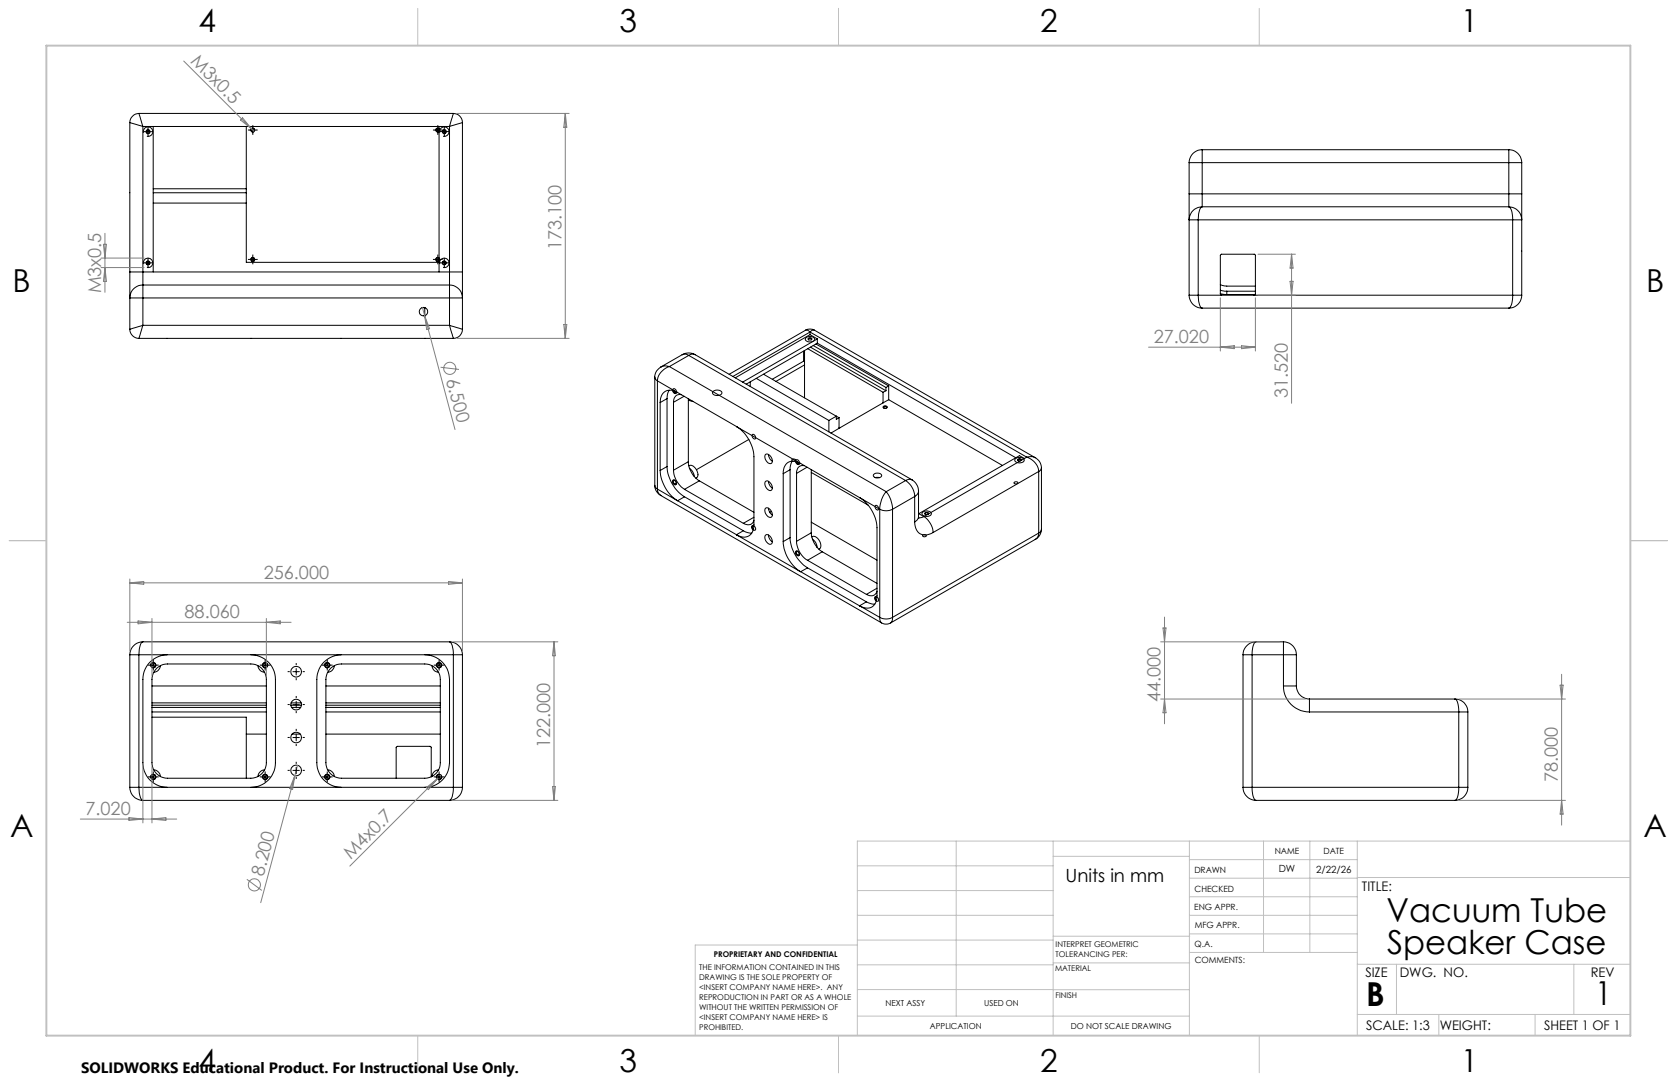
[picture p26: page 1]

NAME | DATE
CHECKED | | | TITLE: Vacuum Tube Speaker Case

Units in mm | DRAWN | DW | 2/22/26

ENG APPR.
MFG APPR.

INTERPRET GEOMETRIC TOLERANCING PER: | Q.A.
MATERIAL | | SIZE B | DWG. NO. | REV 1

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

NEXT ASSY | USED ON | FINISH

APPLICATION | DO NOT SCALE DRAWING | | SCALE: 1:3 | WEIGHT: | SHEET 1 OF 1

SOLIDWORKS Educational Product. For Instructional Use Only.

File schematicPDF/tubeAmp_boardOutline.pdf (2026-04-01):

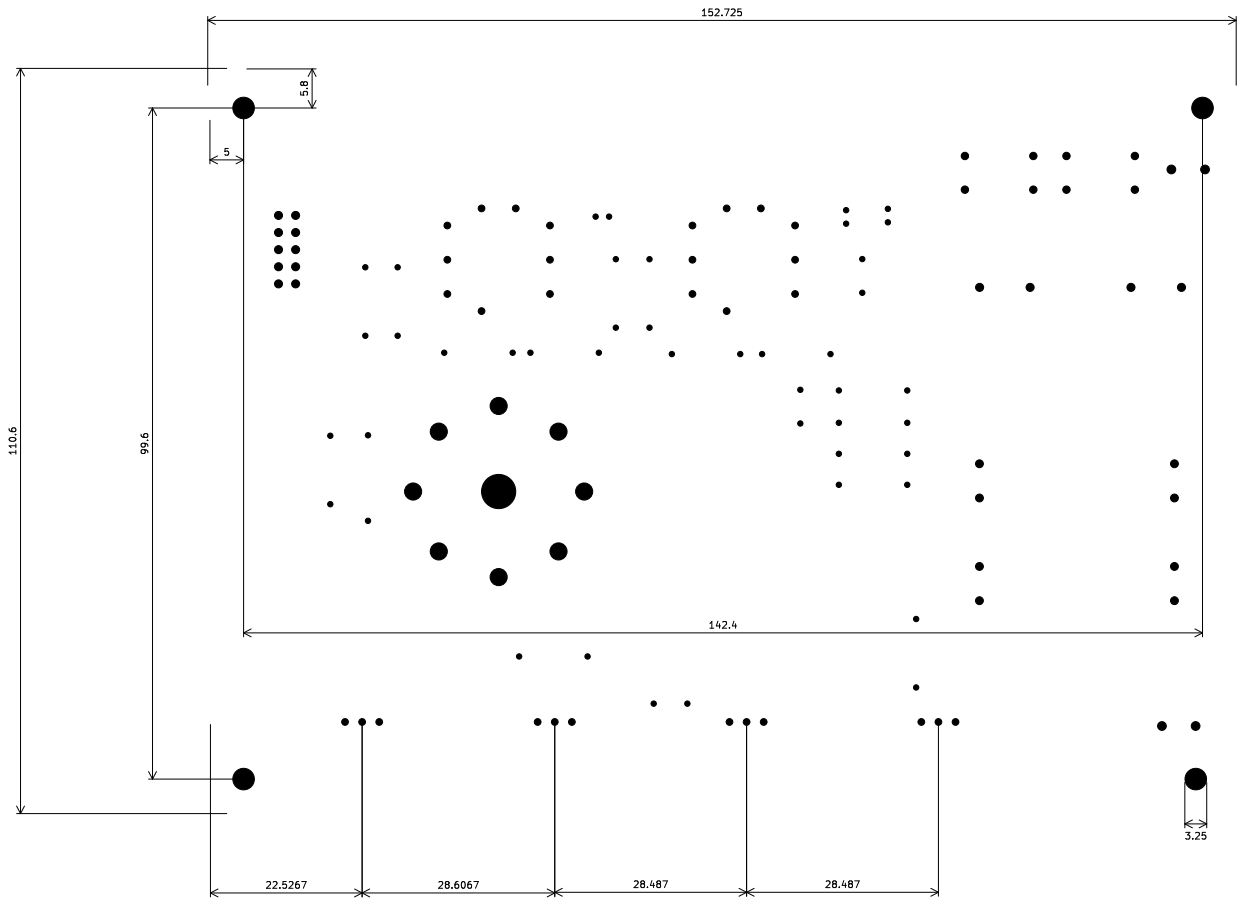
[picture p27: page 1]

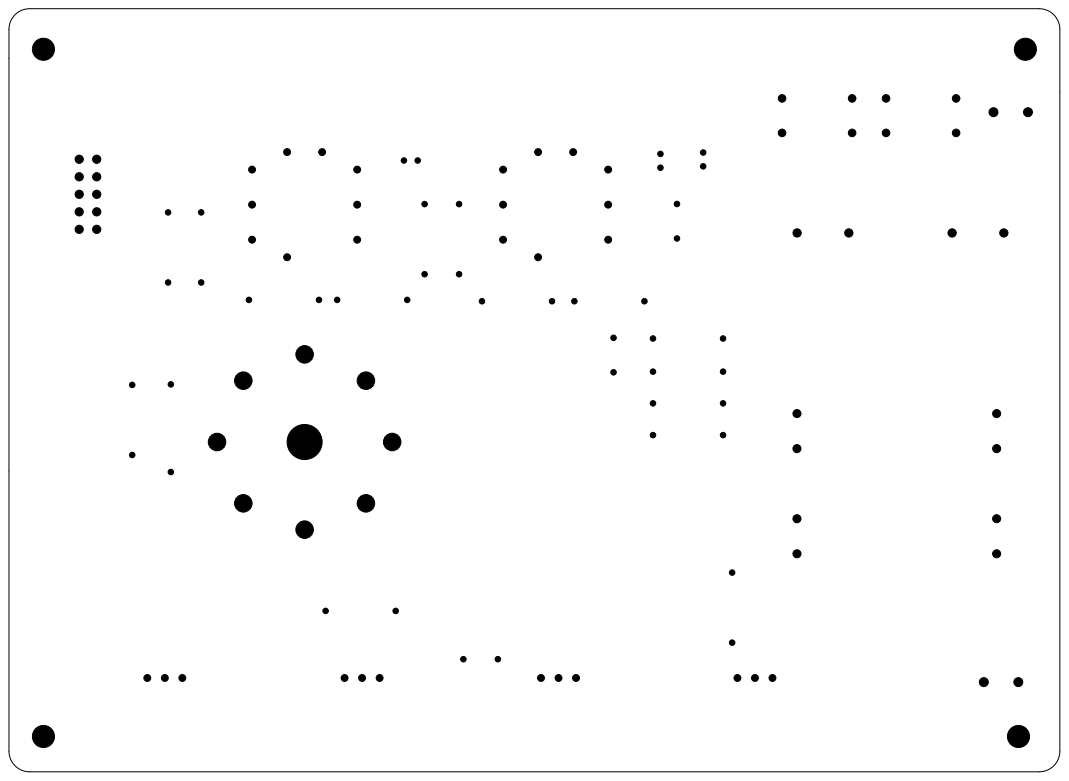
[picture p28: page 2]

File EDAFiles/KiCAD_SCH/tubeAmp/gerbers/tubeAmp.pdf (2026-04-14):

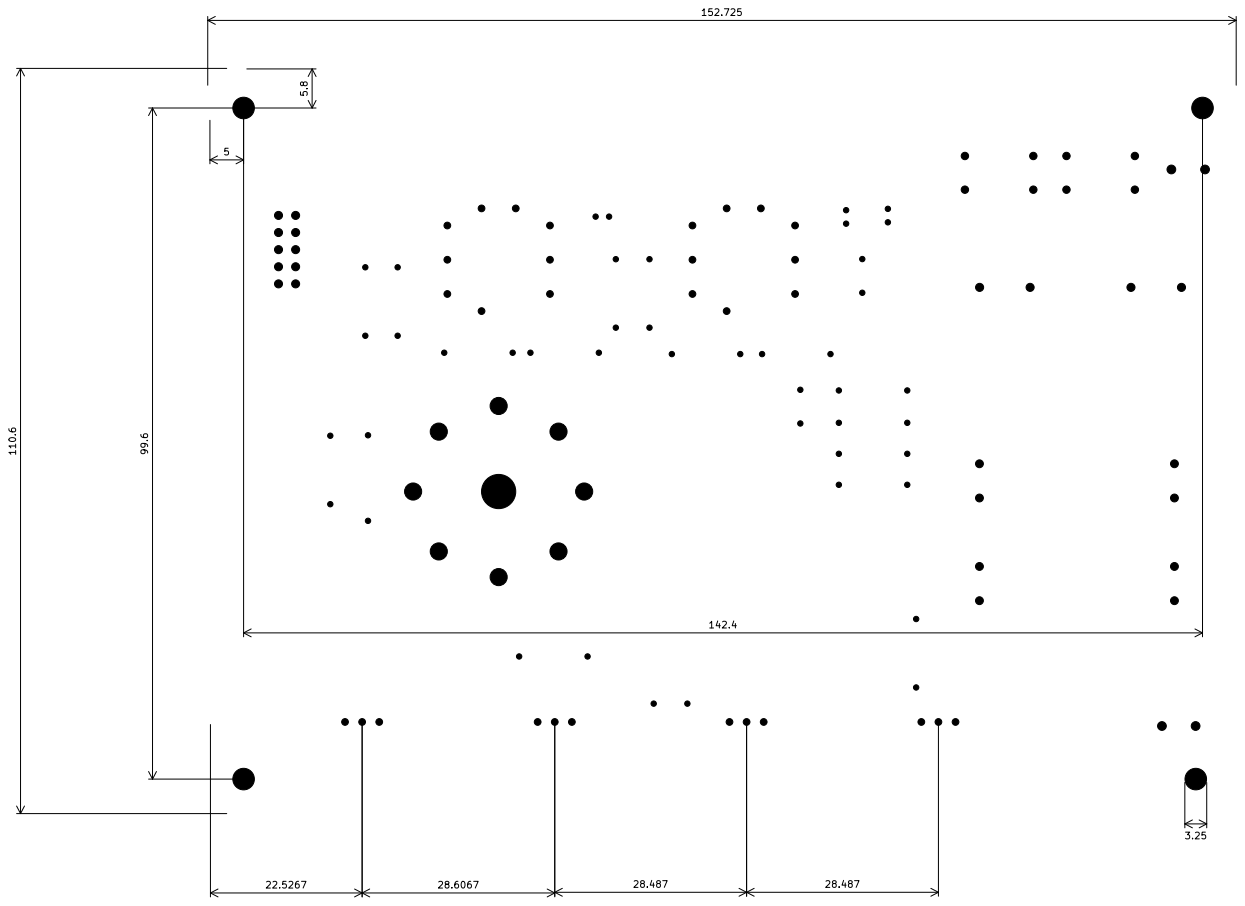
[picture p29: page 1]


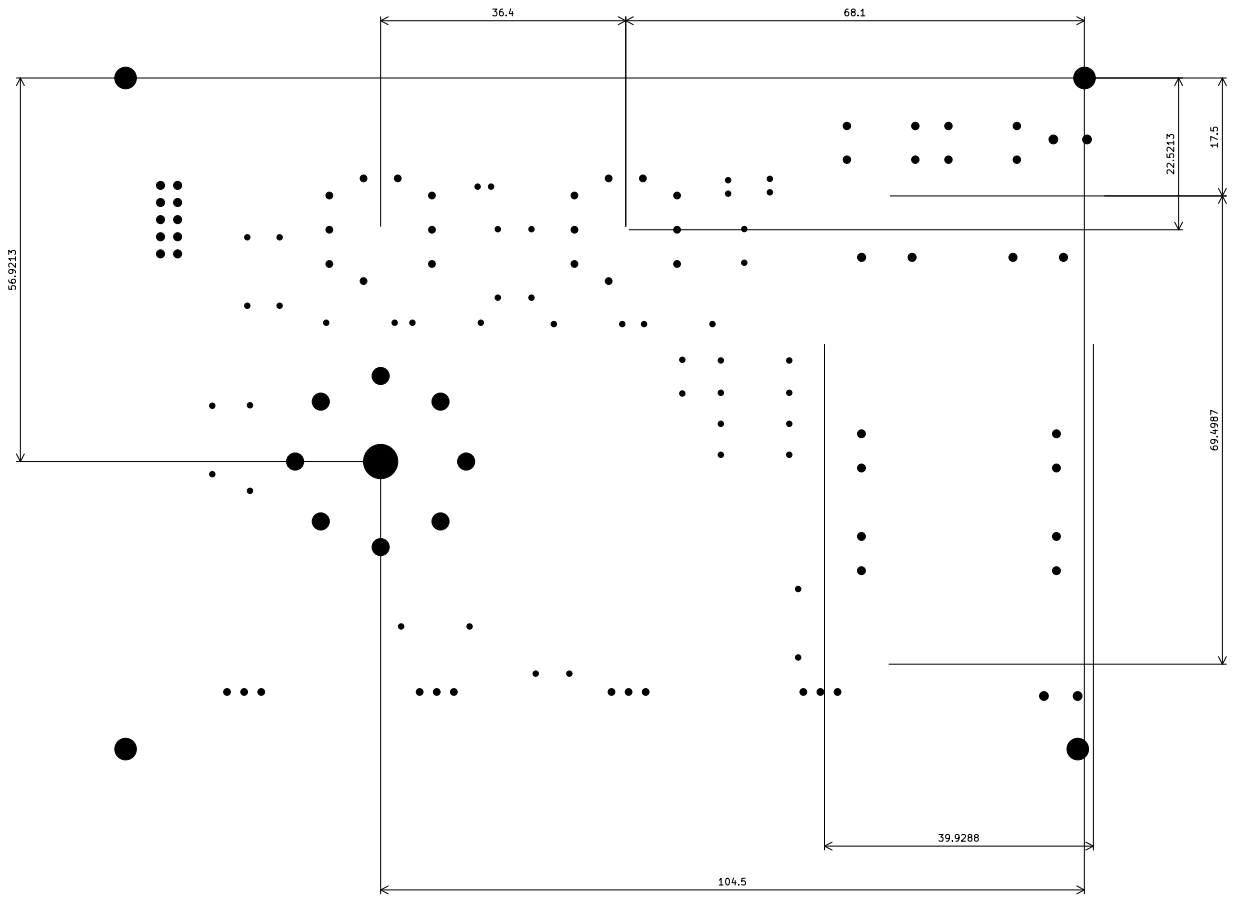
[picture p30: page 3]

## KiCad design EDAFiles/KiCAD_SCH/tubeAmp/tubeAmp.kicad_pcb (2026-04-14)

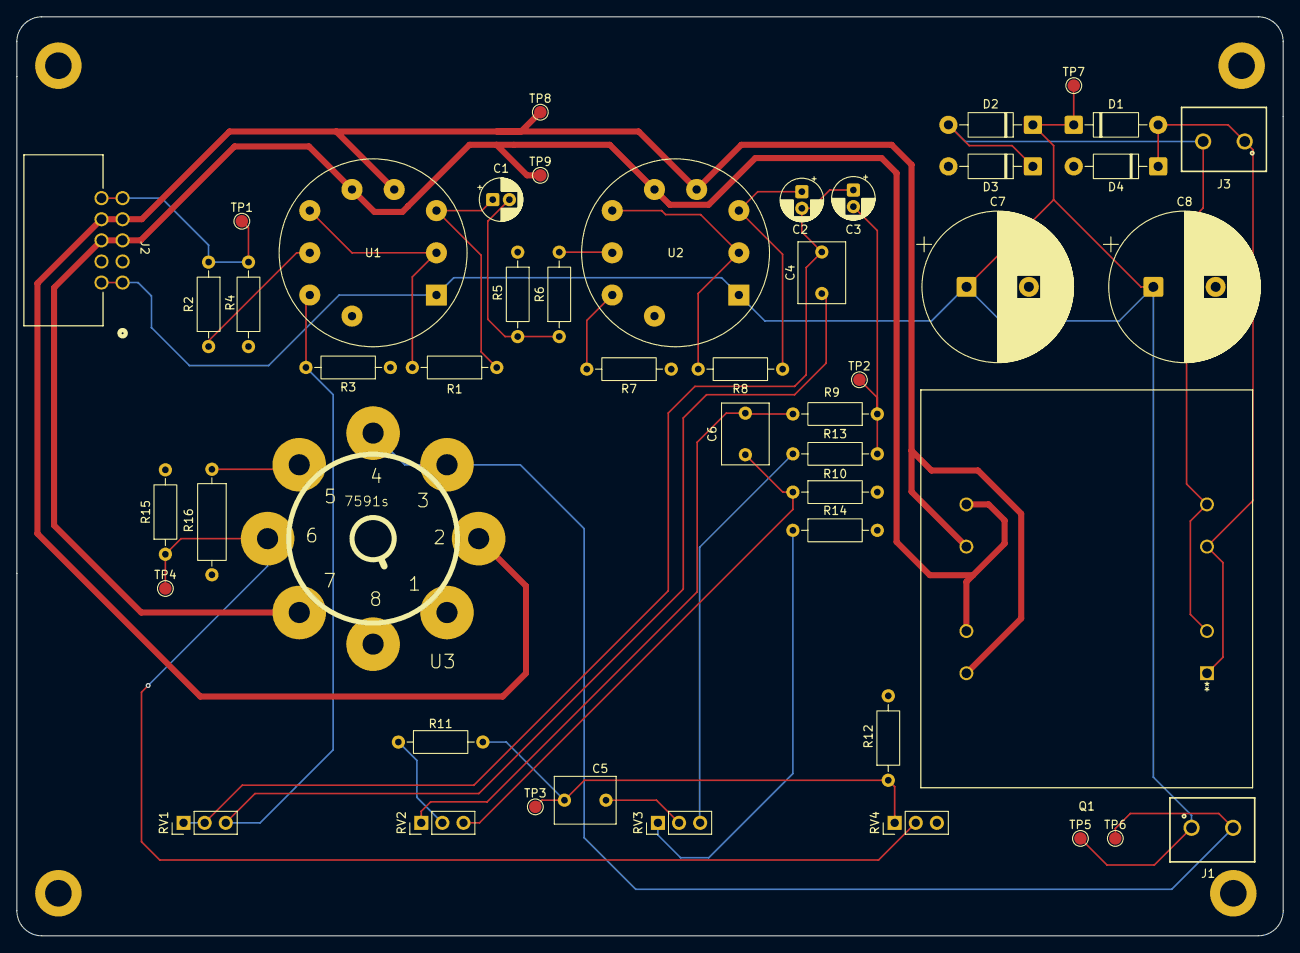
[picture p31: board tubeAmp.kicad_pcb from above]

Board: 2 copper layers, 152.4 x 110.6 mm, 52 parts (0 on the bottom side), 28 nets.

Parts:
C1, C2, C3: 1u, 100V; CP_Radial_D5.0mm_P2.00mm
C4: 200p, 50V; C_Rect_L7.2mm_W5.5mm_P5.00mm_FKS2_FKP2_MKS2_MKP2
C5: 10n, 50V; C_Rect_L7.2mm_W5.5mm_P5.00mm_FKS2_FKP2_MKS2_MKP2
C6: 220n, 50V; C_Rect_L7.2mm_W5.5mm_P5.00mm_FKS2_FKP2_MKS2_MKP2
C7, C8: 470u, 200V; CP_Radial_D18.0mm_P7.50mm
D1, D2, D3, D4: 1N4004; D_DO-41_SOD81_P10.16mm_Horizontal
H1, H2, H3: MountingHole_3.2mm_M3_DIN965_Pad
H4: MountingHole_3.2mm_M3_DIN965_Pad
J1, J3: 691137710002; 691137710002-2screw
J2: 702471054; CONN_7024710xx_10pos
Q1: VPP12-800; TRANS_VPP12-800_TRM
R1, R2, R3, R6, R7, R8: 330, 1/4W; R_Axial_DIN0207_L6.3mm_D2.5mm_P10.16mm_Horizontal
R4, R12: 100K, 1/4W; R_Axial_DIN0207_L6.3mm_D2.5mm_P10.16mm_Horizontal
R5, R15: 560K, 1/4W; R_Axial_DIN0207_L6.3mm_D2.5mm_P10.16mm_Horizontal
R9, R10, R11: 2.2K, 1/4W; R_Axial_DIN0207_L6.3mm_D2.5mm_P10.16mm_Horizontal
R13, R14: 1K, 1/4W; R_Axial_DIN0207_L6.3mm_D2.5mm_P10.16mm_Horizontal
R16: 450, 1/2W; R_Axial_DIN0309_L9.0mm_D3.2mm_P12.70mm_Horizontal
RV1, RV2, RV3, RV4: 10K, 1/4W; PinHeader_1x03_P2.54mm_Vertical
TP1, TP2, TP3, TP4, TP5, TP6, TP7, TP8, TP9: TestPoint; TestPoint_Pad_D1.5mm
U1, U2: ECC88; Valve_Noval_P
U3: 7591s; OCTAL_CENTERHOLE

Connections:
AC+: D1.2 (A), D4.1 (K), J3.1, Q1.1, Q1.3 (4)
AC-: D2.2 (A), D3.1 (K), J3.2, Q1.2 (3), Q1.4 (6)
Aux_in: J2.5, J2.10, R2.1, R4.2, TP1.1
Filament+: J2.4, J2.9, Q1.6 (9), Q1.8 (12), TP8.1, U1.4 (F1), U2.4 (F1), U3.2 (F1)
Filament-: J2.3, J2.8, Q1.5 (7), Q1.7 (10), TP9.1, U1.5 (F2), U2.5 (F2), U3.7 (F2)
GND: C7.2, C8.2, D3.2 (A), D4.2 (A), H3.1, H4.1, J2.2, J2.7, R3.1, R4.1, R5.1, R7.1, R10.2, R12.2, R14.2, R15.2, R16.2, RV4.3
Line_out: C3.2, R9.1, R13.1, TP2.1
unnamed: C1.2, R5.2, R6.1
unnamed: C2.2, C3.1, C4.2, RV1.1, RV1.2
unnamed: C5.2, RV3.2
unnamed: C6.1, R9.2, RV2.1
unnamed: C6.2, R10.1, RV2.3
unnamed: R11.1, RV2.2
unnamed: R13.2, RV3.3
unnamed: R14.1, RV3.1
unnamed: R1.2, U1.2 (G), U1.6 (A)
unnamed: C1.1, R1.1, U1.3 (K)
unnamed: R2.2, U1.7 (G)
unnamed: C4.1, R3.2, RV1.3, U1.8 (K)
unnamed: R8.2, U2.2 (G), U2.6 (A)
unnamed: C2.1, R8.1, U2.3 (K)
unnamed: R6.2, U2.7 (G)
unnamed: R7.2, U2.8 (K)
unnamed: R16.1, U3.5 (F1)
Tone_out: C5.1, R11.2, R12.1, RV4.1, TP3.1
Vol_out: R15.1, RV4.2, TP4.1, U3.6 (G1)
xfmr+: C7.1, C8.1, D1.1 (K), D2.1 (K), J1.1, J2.1, J2.6, TP5.1, TP7.1, U1.1 (A), U2.1 (A)
xfmr-: J1.2, TP6.1, U3.3 (A), U3.4 (G2)

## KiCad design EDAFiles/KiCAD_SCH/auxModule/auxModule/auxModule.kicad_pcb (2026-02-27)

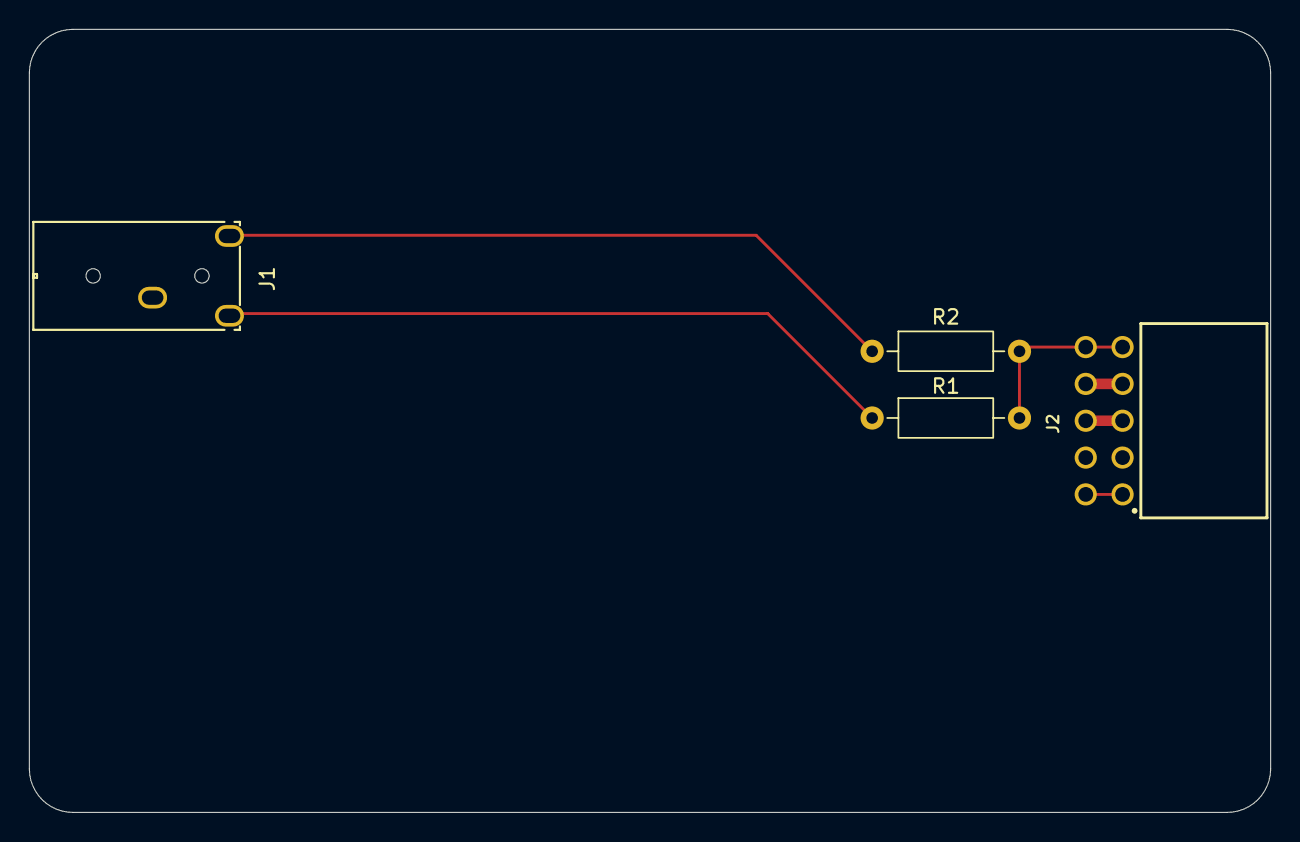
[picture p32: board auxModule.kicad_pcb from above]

Board: 2 copper layers, 85.6 x 54.0 mm, 4 parts (0 on the bottom side), 7 nets.

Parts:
J1: STX-3000; STX-3000_KYC
J2: 6130XX243121_613010243121; 613010243121_10pin
R1, R2: 1K, 1/4W; R_Axial_DIN0207_L6.3mm_D2.5mm_P10.16mm_Horizontal

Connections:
GND: J1.1, J2.3, J2.4
unnamed: J1.2, R1.1
unnamed: J1.3, R2.1
unnamed: J2.9, J2.10, R1.2, R2.2
VPP: J2.1, J2.2
filament+: J2.7, J2.8
filament-: J2.5, J2.6

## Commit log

2025-12-19 Initial Upload
    [auxModule.csv, auxModule.kicad_pcb, auxModule.kicad_sch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]
2026-02-27 Periodic Update from local Machine
    [auxModule-B_Cu.gbr, auxModule-B_Mask.gbr, auxModule-B_Paste.gbr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]
2026-03-08 add problems.txt
    [tubeAmp_BOM.ods]
2026-04-14 Add design requirement docs
    [board-outline.step, tubeAmp.kicad_pcb, tubecase-lid.3MF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]
2026-05-13 Documentation Updates
    [tubeAmp_BOM.ods]
